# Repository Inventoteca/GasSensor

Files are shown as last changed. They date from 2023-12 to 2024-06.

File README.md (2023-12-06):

# Gas Sensor
Sensor de nivel de gas para tanques estacionarios. Se coloca sobre 
el indicador de nivel y transmite las lectura de manera inalámbrica. 
Hay 2 versiones principales: uno que usa LoRa y otro que usa Sigfox.  

La versión LoRa no es viable porque necesita muchas estaciones disponibles.  
La versión Sigfox funciona.  

Debe funcionar durante 3 años continuos usando 2 baterías AA. 
Se necesita un consumo promedio de 4 mA o menos.

El diseño "sensor_sigfox_1.1" es una actualización de la versión 1 del sensor Sigfox. 
Se han realizado cmabios en hardware y software . Los cambios principales son:  
- los módulos están configurados en modo de bajo consumo
- la lectura del voltaje de alimentación se realiza con el hardware interno del microcontrolador (de esta forma se elimina un divisor de voltaje externo)
- cambio de sensor magnético (se descarta el AS5600 y se agrega el MLX90393)
- usar frecuencia de reloj de ultra-bajo consumo (32.768 kHz)
- se puede usar el generador de frecuencia interno, pero también se agrega un cristal y capacitores de carga para commparar el consumo
- eliminar booster
- agregar conector U.FL para antena y pad para soldar antena de alambre opcional (eliminar conector SMA)

El conector U.FL se usa en muchos dispositivos  
https://en.wikipedia.org/wiki/Hirose_U.FL  
https://learn.sparkfun.com/tutorials/three-quick-tips-about-using-ufl/all  
https://www.data-alliance.net/ufl-cables/  

Los cristales más baratos tienen encapsulado cilindrico  
https://www.lcsc.com/product-detail/Crystals_CREC-01-X-TB-11CHJRI032768000_C7462599.html  
Para facilitar el montaje se usarán cristales SMD aunque son un poco más grandes  
https://www.lcsc.com/product-detail/Crystals_huaxindianzi-DP2032K76812001_C17702403.html  

El microcontrolador es ATtiny826 (8kB, family 2, 20 pins). Se usan los siguiente pines:  
- alimentación VCC pin 1, GND pin 20
- I2C (TWI) SDA pin 10 PB1, SCL pin 11 PB0
- cristal TOSC1 pin 8 PB3, TOSC2 pin 9 PB2
- UART hay 2 puertos con pines configurables (Serial y Serial1) con TX, RX, XCK, XDIR en PC0, PC1, PC2, PC3 y PA1, PA2, PA3, PA4
https://datasheet.lcsc.com/lcsc/2309071123_Microchip-Tech-ATTINY826-XU_C3235639.pdf
https://github.com/SpenceKonde/megaTinyCore

Los componentes más baratos están en LCSC, luego DigiKey y en tercer lugar Mouser  

El sensor Hall se puede usar en modo I2C o SPI. Se usará el modo I2C

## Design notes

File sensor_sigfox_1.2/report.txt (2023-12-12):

Info: Procesando el símbolo 'C2:Capacitor_SMD:C_0805_2012Metric_Pad1.18x1.45mm_HandSolder'.
Info: Procesando el símbolo 'U2:Package_DFN_QFN:QFN-16-1EP_3x3mm_P0.5mm_EP1.7x1.7mm'.
Info: Procesando el símbolo 'U1:Package_DFN_QFN:VQFN-20-1EP_3x3mm_P0.4mm_EP1.7x1.7mm'.
Info: Procesando el símbolo 'R4:Resistor_SMD:R_0805_2012Metric_Pad1.20x1.40mm_HandSolder'.
Info: Procesando el símbolo 'R3:Resistor_SMD:R_0805_2012Metric_Pad1.20x1.40mm_HandSolder'.
Info: Procesando el símbolo 'R2:Resistor_SMD:R_0805_2012Metric_Pad1.20x1.40mm_HandSolder'.
Info: Procesando el símbolo 'R1:Resistor_SMD:R_0805_2012Metric_Pad1.20x1.40mm_HandSolder'.
Info: Procesando el símbolo 'J4:Connector_Coaxial:U.FL_Hirose_U.FL-R-SMT-1_Vertical'.
Info: Procesando el símbolo 'J3:Connector_Pin:Pin_D0.9mm_L10.0mm_W2.4mm_FlatFork'.
Info: Procesando el símbolo 'J2:Connector_PinHeader_2.54mm:PinHeader_1x07_P2.54mm_Vertical'.
Info: Procesando el símbolo 'IC1:WSSFM11R2DAT:WSSFM11R2DAT'.
Info: Procesando el símbolo 'J1:Battery:BatteryHolder_Keystone_2468_2xAAA'.
Info: Procesando el símbolo 'C3:Capacitor_SMD:C_0805_2012Metric_Pad1.18x1.45mm_HandSolder'.
Info: Procesando el símbolo 'C1:Capacitor_SMD:C_0805_2012Metric_Pad1.18x1.45mm_HandSolder'.
Info: Procesando el símbolo 'Y1:Crystal:Crystal_C26-LF_D2.1mm_L6.5mm_Vertical'.
Info: Procesando el símbolo 'C4:Capacitor_SMD:C_0805_2012Metric_Pad1.18x1.45mm_HandSolder'.
Info: Procesando el símbolo 'C5:Capacitor_SMD:C_0805_2012Metric_Pad1.18x1.45mm_HandSolder'.
Info: Procesando el símbolo 'C6:Capacitor_SMD:C_0805_2012Metric_Pad1.18x1.45mm_HandSolder'.
Info: Procesando el símbolo 'D1:LED_SMD:LED_0603_1608Metric_Pad1.05x0.95mm_HandSolder'.
U1 pin 11 reconectado de /SCL a Net-(U1-PB0).
U1 pin 12 reconectado de unconnected-(U1-PC0-Pad12) a Net-(U1-PB2).
U1 pin 13 reconectado de unconnected-(U1-PC1-Pad13) a /SDA.
U1 pin 14 reconectado de unconnected-(U1-PC2-Pad14) a /SCL.
Añadir red unconnected-(U1-PC0-Pad15).
U1 pin 15 reconectado de unconnected-(U1-PC3-Pad15) a unconnected-(U1-PC0-Pad15).
Añadir red unconnected-(U1-PC1-Pad16).
U1 pin 16 reconectado de Net-(U1-~{RESET}/PA0) a unconnected-(U1-PC1-Pad16).
Añadir red unconnected-(U1-PC2-Pad17).
U1 pin 17 reconectado de /SF_RX a unconnected-(U1-PC2-Pad17).
Añadir red unconnected-(U1-PC3-Pad18).
U1 pin 18 reconectado de /SF_TX a unconnected-(U1-PC3-Pad18).
U1 pin 19 reconectado de unconnected-(U1-PA3-Pad19) a Net-(U1-~{RESET}/PA0).
U1 pin 20 reconectado de GND a /SF_RX.
U1 pin 21 conectado a GND.
Y1 pin 1 reconectado de Net-(U1-PB3) a Net-(U1-PB0).
U1 pin 5 reconectado de unconnected-(U1-PA7-Pad5) a Net-(U1-PA4).
Añadir red Net-(U1-PB0).
C3 pin 2 reconectado de Net-(U1-PB3) a Net-(U1-PB0).
Huella U1 cambiada de 'Package_DFN_QFN:QFN-24-1EP_3x3mm_P0.4mm_EP1.75x1.6mm_ThermalVias' a 'Package_DFN_QFN:VQFN-20-1EP_3x3mm_P0.4mm_EP1.7x1.7mm'.
U1 propiedades actualizadas.
U1 pin 1 reconectado de VCC a /SF_TX.
Añadir red unconnected-(U1-PA3-Pad2).
U1 pin 2 reconectado de Net-(U1-PA4) a unconnected-(U1-PA3-Pad2).
U1 pin 3 reconectado de unconnected-(U1-PA5-Pad3) a GND.
U1 pin 4 reconectado de Net-(IC1-RST_N) a VCC.
U1 pin 10 reconectado de /SDA a unconnected-(U1-PB4-Pad10).
Añadir red unconnected-(U1-PA5-Pad6).
U1 pin 6 reconectado de unconnected-(U1-PB5-Pad6) a unconnected-(U1-PA5-Pad6).
U1 pin 7 reconectado de unconnected-(U1-PB4-Pad7) a Net-(IC1-RST_N).
Añadir red unconnected-(U1-PA7-Pad8).
U1 pin 8 reconectado de Net-(U1-PB3) a unconnected-(U1-PA7-Pad8).
Añadir red unconnected-(U1-PB5-Pad9).
U1 pin 9 reconectado de Net-(U1-PB2) a unconnected-(U1-PB5-Pad9).
Añadir red unconnected-(U1-PB4-Pad10).

Info: Número de avisos: 0, errores: 0.

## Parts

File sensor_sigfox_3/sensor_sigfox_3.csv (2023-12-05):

Id | Designator | Package | Quantity | Designation | Supplier and ref
1 | C7,C3 | C_0805_2012Metric_Pad1.18x1.45mm_HandSolder | 2 | 22u
2 | L2 | L_0603_1608Metric_Pad1.05x0.95mm_HandSolder | 1 | 47n
3 | R14 | R_0603_1608Metric_Pad0.98x0.95mm_HandSolder | 1 | 0
4 | R13,R12,R6 | R_0603_1608Metric_Pad0.98x0.95mm_HandSolder | 3 | 330
5 | R11 | R_0603_1608Metric_Pad0.98x0.95mm_HandSolder | 1 | 2k
6 | R10,R7 | R_0603_1608Metric_Pad0.98x0.95mm_HandSolder | 2 | 10k
7 | R9,R3 | R_0603_1608Metric_Pad0.98x0.95mm_HandSolder | 2 | 100k
8 | R8,R1 | R_0603_1608Metric_Pad0.98x0.95mm_HandSolder | 2 | 470
9 | R5,R4 | R_0603_1608Metric_Pad0.98x0.95mm_HandSolder | 2 | 2.2k
10 | R2 | R_0603_1608Metric_Pad0.98x0.95mm_HandSolder | 1 | 220k
11 | C8 | C_0603_1608Metric_Pad1.08x0.95mm_HandSolder | 1 | 100p
12 | C6,C4 | C_0603_1608Metric_Pad1.08x0.95mm_HandSolder | 2 | 10u
13 | C5,C2,C1 | C_0603_1608Metric_Pad1.08x0.95mm_HandSolder | 3 | 100n
14 | L1 | L_Murata_LQH55DN_5.7x5.0mm | 1 | 4.7u
15 | J3 | PinHeader_1x03_P2.54mm_Vertical | 1 | debug
16 | D2 | D_SMA | 1 | SD103
17 | J1 | PinHeader_1x03_P2.54mm_Vertical | 1 | UDPI
18 | J2 | PinHeader_1x02_P2.54mm_Horizontal | 1 | Battery
19 | JP1 | SolderJumper-3_P1.3mm_Open_Pad1.0x1.5mm | 1 | Jumper_3_Open
20 | IC2 | WSSFM11R2DAT | 1 | WSSFM11R2DAT
21 | D1,D3,D4 | LED_0603_1608Metric_Pad1.05x0.95mm_HandSolder | 3 | LED_Small
22 | U3 | SOT-23-6 | 1 | MT3608
23 | IC1 | SOIC127P600X175-8N | 1 | AS5600-ASOM
24 | Q1 | TSOT-23-6 | 1 | DMC2053UVT
25 | U2 | SSOP-20_5.3x7.2mm_P0.65mm | 1 | ATtiny826-X

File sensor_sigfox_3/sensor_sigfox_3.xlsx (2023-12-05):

Id | Designator | Package | Quantity | Designation | Supplier and ref
1 | C5,C2,C1 | C_0603_1608Metric_Pad1.08x0.95mm_HandSolder | 3 | 100n
2 | C6,C4 | C_0603_1608Metric_Pad1.08x0.95mm_HandSolder | 2 | 10u
3 | C7,C3 | C_0805_2012Metric_Pad1.18x1.45mm_HandSolder | 2 | 22u
4 | C8 | C_0603_1608Metric_Pad1.08x0.95mm_HandSolder | 1 | 100p
5 | D1,D3,D4 | LED_0603_1608Metric_Pad1.05x0.95mm_HandSolder | 3 | LED_Small
6 | D2 | D_SMA | 1 | SS24
7 | IC1 | SOIC127P600X175-8N | 1 | AS5600-ASOM
8 | IC2 | WSSFM11R2DAT | 1 | WSSFM11R2DAT
9 | J1 | PinHeader_1x03_P2.54mm_Vertical | 1 | UDPI
10 | J2 | PinHeader_1x02_P2.54mm_Horizontal | 1 | Battery
11 | J3 | PinHeader_1x03_P2.54mm_Vertical | 1 | debug
12 | JP1 | SolderJumper-3_P1.3mm_Open_Pad1.0x1.5mm | 1 | Jumper_3_Open
13 | L1 | L_Murata_LQH55DN_5.7x5.0mm | 1 | 4.7u | https://www.lcsc.com/product-detail/Inductors-SMD_BC-Bao-Cheng-Elec-BCIHP0420SC-4R7M_C2921168.html
14 | L2 | L_0603_1608Metric_Pad1.05x0.95mm_HandSolder | 1 | 47n
15 | Q1 | TSOT-23-6 | 1 | DMC2053UVT
16 | R10,R7 | R_0603_1608Metric_Pad0.98x0.95mm_HandSolder | 2 | 10k
17 | R11 | R_0603_1608Metric_Pad0.98x0.95mm_HandSolder | 1 | 2k
18 | R13,R12,R6 | R_0603_1608Metric_Pad0.98x0.95mm_HandSolder | 3 | 330
19 | R14 | R_0603_1608Metric_Pad0.98x0.95mm_HandSolder | 1 | 0
20 | R2 | R_0603_1608Metric_Pad0.98x0.95mm_HandSolder | 1 | 220k
21 | R5,R4 | R_0603_1608Metric_Pad0.98x0.95mm_HandSolder | 2 | 2.2k
22 | R8,R1 | R_0603_1608Metric_Pad0.98x0.95mm_HandSolder | 2 | 470
23 | R9,R3 | R_0603_1608Metric_Pad0.98x0.95mm_HandSolder | 2 | 100k
24 | U2 | SSOP-20_5.3x7.2mm_P0.65mm | 1 | ATtiny826-X
25 | U3 | SOT-23-6 | 1 | MT3608

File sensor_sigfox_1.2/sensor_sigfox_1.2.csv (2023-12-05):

Id | Designator | Package | Quantity | Designation | Supplier and ref
1 | R13,R12,R6 | R_0805_2012Metric_Pad1.20x1.40mm_HandSolder | 3 | 330
2 | J1 | PinHeader_1x03_P2.54mm_Vertical | 1 | UDPI
3 | J2 | PinHeader_1x02_P2.54mm_Horizontal | 1 | Battery
4 | JP1 | SolderJumper-3_P1.3mm_Open_Pad1.0x1.5mm | 1 | Jumper_3_Open
5 | C6,C4 | C_0805_2012Metric_Pad1.18x1.45mm_HandSolder | 2 | 10u
6 | C5,C1,C2 | C_0805_2012Metric_Pad1.18x1.45mm_HandSolder | 3 | 100n
7 | IC2 | WSSFM11R2DAT | 1 | WSSFM11R2DAT
8 | D1,D3,D4 | LED_0603_1608Metric_Pad1.05x0.95mm_HandSolder | 3 | LED_Small
9 | J4 | SMA_Samtec_SMA-J-P-X-ST-EM1_EdgeMount | 1 | Conn_Coaxial
10 | D2 | D_SOD-323_HandSoldering | 1 | SD103
11 | U3 | SOT-23-6 | 1 | MT3608
12 | R2 | R_0805_2012Metric_Pad1.20x1.40mm_HandSolder | 1 | 220k
13 | R9,R3 | R_0805_2012Metric_Pad1.20x1.40mm_HandSolder | 2 | 100k
14 | R10,R7 | R_0805_2012Metric_Pad1.20x1.40mm_HandSolder | 2 | 10k
15 | IC1 | SOIC127P600X175-8N | 1 | AS5600-ASOM
16 | Q1 | TSOT-23-6 | 1 | DMC2053UVT
17 | C7,C3 | C_0805_2012Metric_Pad1.18x1.45mm_HandSolder | 2 | 22u
18 | R1,R8 | R_0805_2012Metric_Pad1.20x1.40mm_HandSolder | 2 | 470
19 | R5,R4 | R_0805_2012Metric_Pad1.20x1.40mm_HandSolder | 2 | 2.2k
20 | U2 | SSOP-20_5.3x7.2mm_P0.65mm | 1 | ATtiny826-X
21 | L1 | L_0805_2012Metric_Pad1.15x1.40mm_HandSolder | 1 | 4.7u
22 | R11 | R_0805_2012Metric_Pad1.20x1.40mm_HandSolder | 1 | 2k

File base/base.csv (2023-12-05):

Id | Designator | Package | Quantity | Designation | Supplier and ref
1 | R7,R4,R3,R9,R5,R2,R8 | R_0805_2012Metric_Pad1.20x1.40mm_HandSolder | 7 | 10k
2 | C6,C1,C4 | C_0805_2012Metric_Pad1.18x1.45mm_HandSolder | 3 | 10u
3 | C8,C3,C7,C5 | C_0805_2012Metric_Pad1.18x1.45mm_HandSolder | 4 | 0.1u
4 | J3 | PinSocket_1x04_P2.54mm_Vertical | 1 | PROG
5 | SW2 | SW_Push_1P1T_NO_6x6mm_H9.5mm | 1 | Flash
6 | SW1 | SW_Push_1P1T_NO_6x6mm_H9.5mm | 1 | Reset
7 | R6,R1 | R_0805_2012Metric_Pad1.20x1.40mm_HandSolder | 2 | 150
8 | J2 | SMA_Samtec_SMA-J-P-X-ST-EM1_EdgeMount | 1 | RF
9 | U3 | Ai-Thinker-Ra-01-LoRa | 1 | Ai-Thinker-Ra-01
10 | U1 | TO-252-2 | 1 | AZ1117D-ADJ
11 | J1 | BarrelJack_Horizontal | 1 | Supply
12 | C2 | C_0805_2012Metric_Pad1.18x1.45mm_HandSolder | 1 | 22u
13 | U2 | ESP-07 | 1 | ESP-07

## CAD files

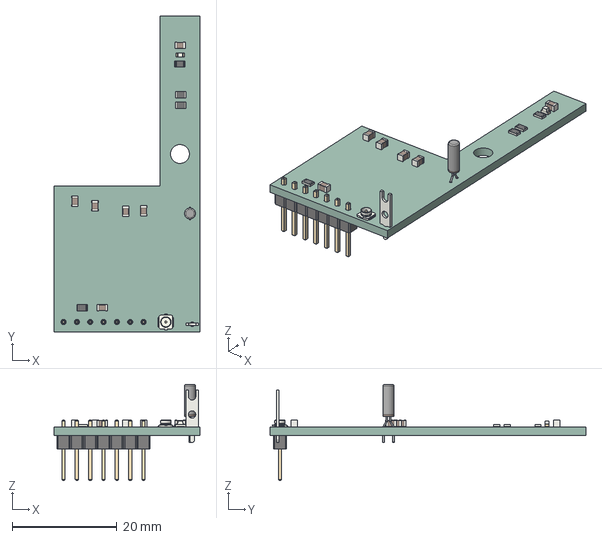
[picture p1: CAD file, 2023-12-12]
sensor_sigfox_1.2/sensor_sigfox_1.2.step
27.8 x 60.1 x 18.3 mm
_autosave-sensor_sigfox_1.1 PCB

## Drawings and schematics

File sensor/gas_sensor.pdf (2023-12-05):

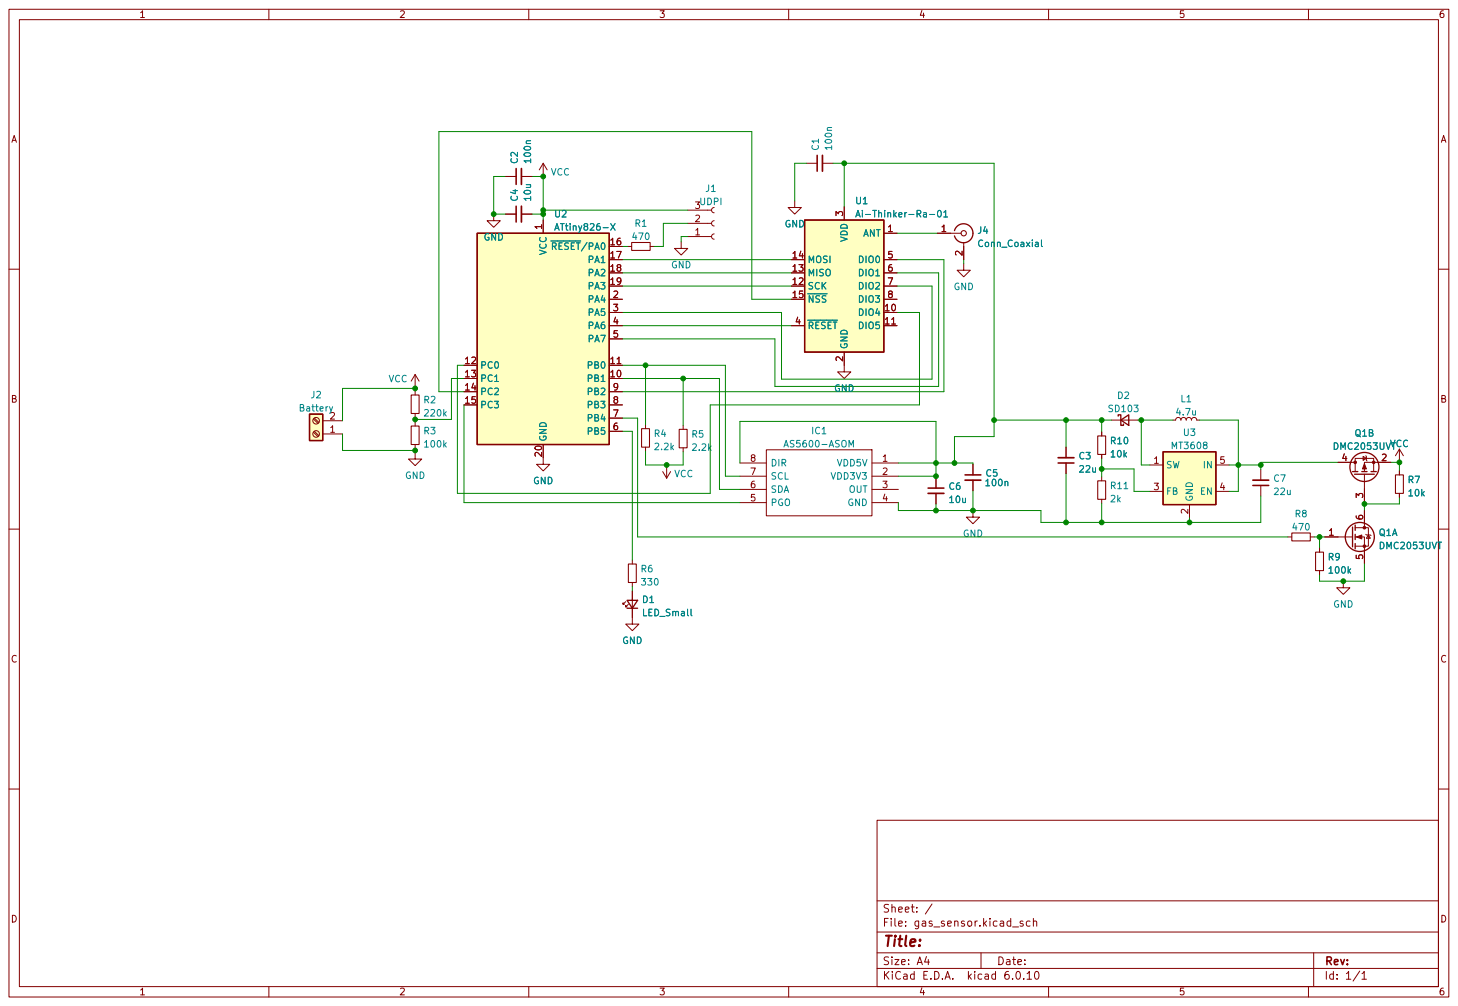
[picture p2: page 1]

1 PB1 10 PB0 11 PC0 12 PC1 13 PC2 14 PC3 15 ~{RESET}/PA016 PA1 17 PA2 18 PA3 19 PA4 2 GND 20 PA5 3 PA6 4 PA7 5 PB5 6 PB4 7 PB3 8 PB2 9 GND C410u C2100n GND

3 ~{RESET} 4 DIO0 5 DIO1 6 DIO2 7 DIO3 8 U1Ai-Thinker-Ra-01 GND

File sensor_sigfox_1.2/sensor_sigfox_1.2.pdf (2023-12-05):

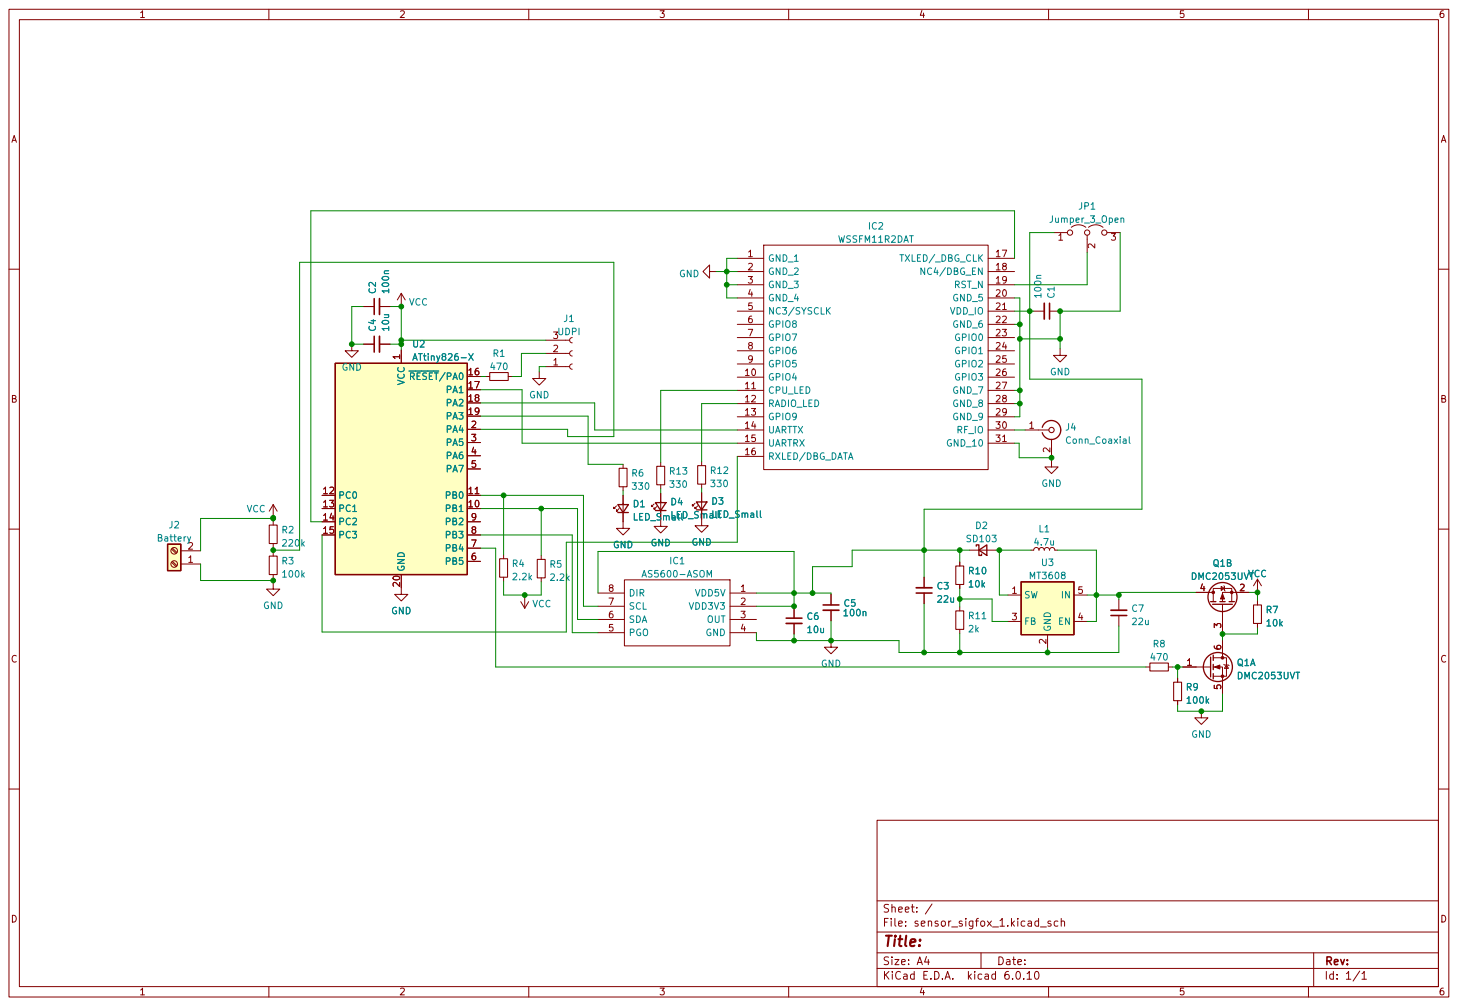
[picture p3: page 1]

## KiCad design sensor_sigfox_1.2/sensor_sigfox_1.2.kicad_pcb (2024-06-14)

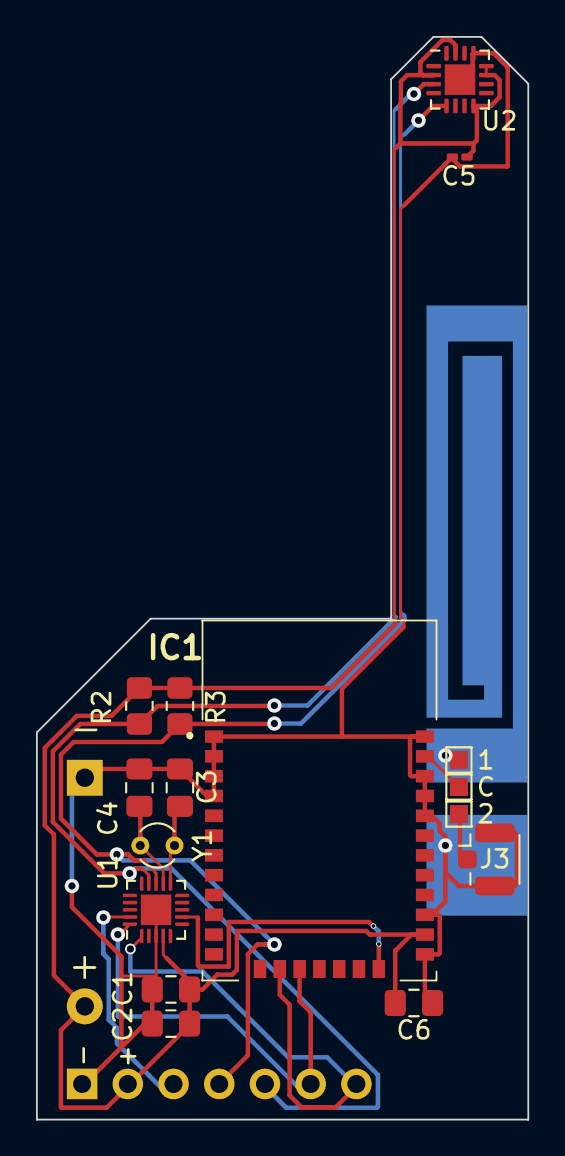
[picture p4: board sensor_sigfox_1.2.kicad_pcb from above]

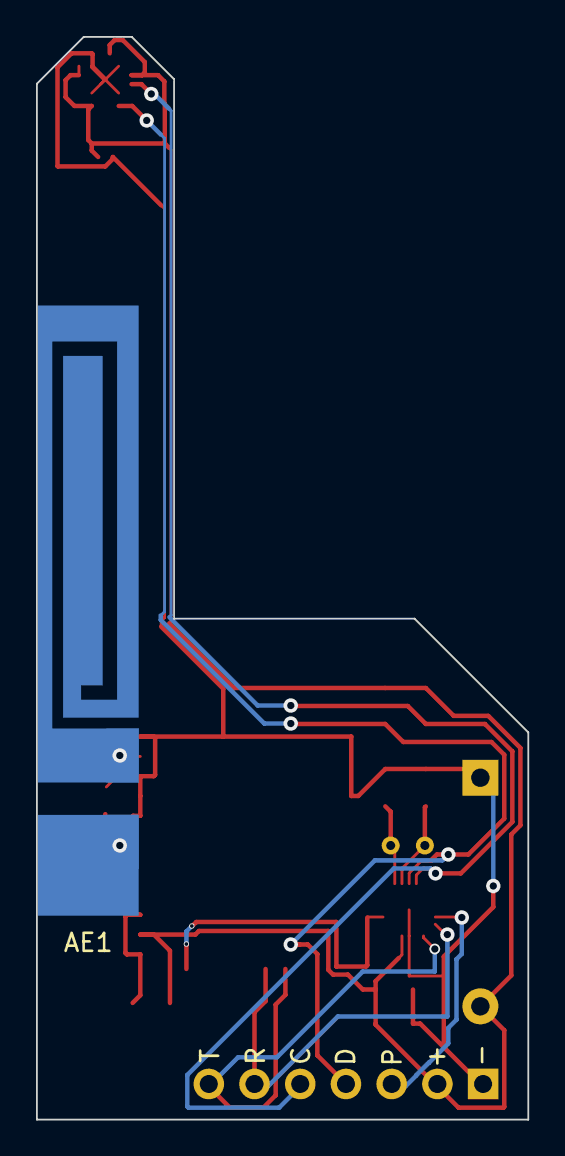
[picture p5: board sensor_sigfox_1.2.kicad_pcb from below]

Board: 2 copper layers, 27.3 x 60.1 mm, 19 parts (2 on the bottom side), 13 nets.

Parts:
1, 2: TestPoint; TestPoint_Pad_1.0x1.0mm
AE1: Antenna_Shield; antena1
C: TestPoint; TestPoint_Pad_1.0x1.0mm
C1: 10u; C_0805_2012Metric_Pad1.18x1.45mm_HandSolder
C2, C6: 100n; C_0805_2012Metric_Pad1.18x1.45mm_HandSolder
C3, C4: 20p; C_0805_2012Metric_Pad1.18x1.45mm_HandSolder
C5: 100n; C_0201_0603Metric_Pad0.64x0.40mm_HandSolder
IC1: WSSFM11R2DAT
J1: Battery; BatteryHolder_Keystone_2468_2xAAA
J2: Conn_01x07_Socket; PinHeader_1x07_P2.54mm_Vertical
J3: Conn_Coaxial; U.FL_Hirose_U.FL-R-SMT-1_Vertical
R2, R3: 2.2k; R_0805_2012Metric_Pad1.20x1.40mm_HandSolder
U1: ATtiny826-X; VQFN-20-1EP_3x3mm_P0.4mm_EP1.7x1.7mm
U2: MLX90393; QFN-16-1EP_3x3mm_P0.5mm_EP1.7x1.7mm
Y1: 32.768 kHz; Crystal_C26-LF_D2.1mm_L6.5mm_Vertical

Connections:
/SCL: J2.5, R2.1, U1.14 (PB0), U2.3 (SCL/SCLK)
/SDA: J2.4, R3.1, U1.13 (PB1), U2.5 (SDA/MOSI)
/SF_RX: IC1.15 (UARTRX), J2.6, U1.20 (PA1)
/SF_TX: IC1.14 (UARTTX), J2.7, U1.1 (PA2)
GND: AE1.2 (Shield), C1.1, C2.1, C3.1, C4.1, C5.1, C6.1, IC1.1 (GND_1), IC1.2 (GND_2), IC1.3 (GND_3), IC1.4 (GND_4), IC1.20 (GND_5), IC1.22 (GND_6), IC1.27 (GND_7), IC1.28 (GND_8), IC1.29 (GND_9), IC1.31 (GND_10), J1.1, J2.1, J3.2 (Ext), U1.3 (GND), U1.21 (GND), U2.13 (VSS), U2.17 (PAD)
unnamed: 1.1, AE1.1 (A)
unnamed: C.1, IC1.30 (RF_IO)
unnamed: IC1.19 (RST_N), U1.7 (PA6)
unnamed: J2.3, U1.19 (~RESET/PA0)
unnamed: 2.1, J3.1 (In)
unnamed: C4.2, U1.12 (PB2), Y1.2
unnamed: C3.2, U1.11 (PB3), Y1.1
VCC: C1.2, C2.2, C5.2, C6.2, IC1.21 (VDD_IO), J1.2, J2.2, R2.2, R3.2, U1.4 (VCC), U2.2 (MS/CS), U2.8 (VDD_IO), U2.11 (A1), U2.12 (A0), U2.15 (VDD)

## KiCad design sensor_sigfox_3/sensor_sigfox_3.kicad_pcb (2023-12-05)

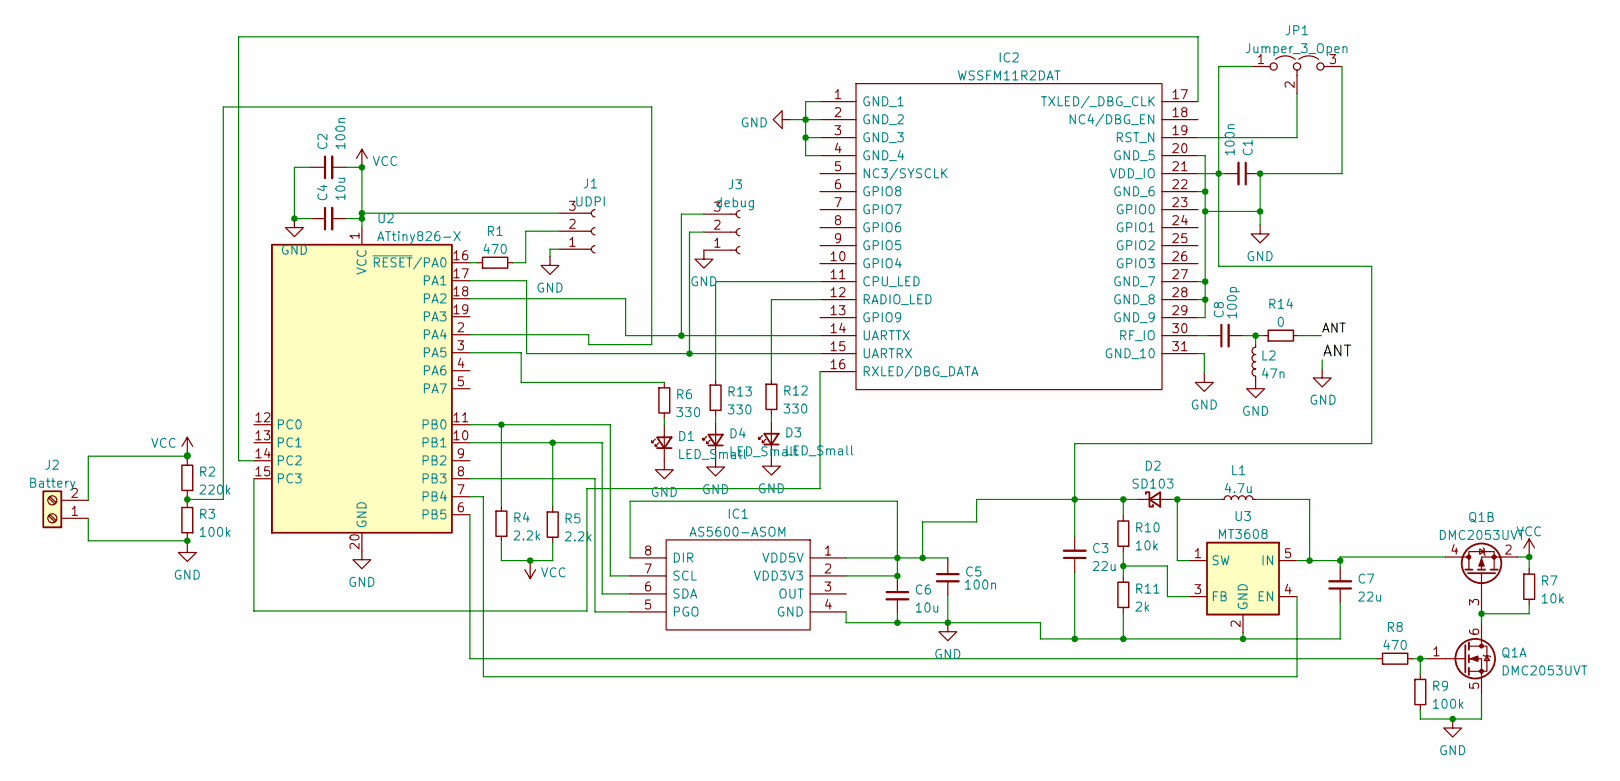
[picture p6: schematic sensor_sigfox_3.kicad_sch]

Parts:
C1, C2, C5: 100n; C_0603_1608Metric_Pad1.08x0.95mm_HandSolder
C3, C7: 22u; C_0805_2012Metric_Pad1.18x1.45mm_HandSolder
C4, C6: 10u; C_0603_1608Metric_Pad1.08x0.95mm_HandSolder
C8: 100p; C_0603_1608Metric_Pad1.08x0.95mm_HandSolder
D1, D3, D4: LED_Small; LED_0603_1608Metric_Pad1.05x0.95mm_HandSolder
D2: SD103; D_SMA
IC1: AS5600-ASOM; SOIC127P600X175-8N; Manufacturer_Part_Number AS5600-ASOM; Mouser Part Number 985-AS5600-ASOM
IC2: WSSFM11R2DAT; Manufacturer_Part_Number WSSFM11R2DAT
J1: UDPI; PinHeader_1x03_P2.54mm_Vertical
J2: Battery; PinHeader_1x02_P2.54mm_Horizontal
J3: debug; PinHeader_1x03_P2.54mm_Vertical
JP1: Jumper_3_Open; SolderJumper-3_P1.3mm_Open_Pad1.0x1.5mm
L1: 4.7u; L_Murata_LQH55DN_5.7x5.0mm
L2: 47n; L_0603_1608Metric_Pad1.05x0.95mm_HandSolder
Q1: DMC2053UVT; TSOT-23-6
R1, R8: 470; R_0603_1608Metric_Pad0.98x0.95mm_HandSolder
R2: 220k; R_0603_1608Metric_Pad0.98x0.95mm_HandSolder
R3, R9: 100k; R_0603_1608Metric_Pad0.98x0.95mm_HandSolder
R4, R5: 2.2k; R_0603_1608Metric_Pad0.98x0.95mm_HandSolder
R6, R12, R13: 330; R_0603_1608Metric_Pad0.98x0.95mm_HandSolder
R7, R10: 10k; R_0603_1608Metric_Pad0.98x0.95mm_HandSolder
R11: 2k; R_0603_1608Metric_Pad0.98x0.95mm_HandSolder
R14: 0; R_0603_1608Metric_Pad0.98x0.95mm_HandSolder
U2: ATtiny826-X; SSOP-20_5.3x7.2mm_P0.65mm
U3: MT3608; SOT-23-6

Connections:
GND: C1.1, C2.1, C3.1, C4.1, C5.2, C6.2, C7.1, D1.1 (K), D3.1 (K), D4.1 (K), IC1.4 (GND), IC2.1 (GND_1), IC2.2 (GND_2), IC2.3 (GND_3), IC2.4 (GND_4), IC2.20 (GND_5), IC2.22 (GND_6), IC2.27 (GND_7), IC2.28 (GND_8), IC2.29 (GND_9), IC2.31 (GND_10), J1.1, J2.1, J3.1, JP1.3 (B), L2.1, Q1.5 (S), R3.1, R9.2, R11.1, R14.2, U2.20 (GND), U3.2 (GND)
unnamed: C1.2, C3.2, C5.1, C6.1, D2.1 (K), IC1.1 (VDD5V), IC1.2 (VDD3V3), IC1.8 (DIR), IC2.21 (VDD_IO), JP1.1 (A), R10.2
unnamed: C7.2, L1.2, Q1.4 (D), U3.5 (IN)
unnamed: C8.2, L2.2, R14.1
unnamed: D1.2 (A), R6.2
unnamed: D2.2 (A), L1.1, U3.1 (SW)
unnamed: D3.2 (A), R12.2
unnamed: D4.2 (A), R13.2
unnamed: IC1.5 (PGO), U2.8 (PB3)
unnamed: IC1.6 (SDA), R5.1, U2.10 (PB1)
unnamed: IC1.7 (SCL), R4.1, U2.11 (PB0)
unnamed: IC2.11 (CPU_LED), R13.1
unnamed: IC2.12 (RADIO_LED), R12.1
unnamed: IC2.14 (UARTTX), J3.3, U2.18 (PA2)
unnamed: IC2.15 (UARTRX), J3.2, U2.17 (PA1)
unnamed: IC2.16 (RXLED/DBG_DATA), U2.15 (PC3)
unnamed: IC2.17 (TXLED/_DBG_CLK), U2.14 (PC2)
unnamed: IC2.19 (RST_N), JP1.2 (C)
unnamed: C8.1, IC2.30 (RF_IO)
unnamed: J1.2, R1.2
unnamed: Q1.1 (G), R8.2, R9.1
unnamed: Q1.3 (G), Q1.6 (D), R7.2
unnamed: R1.1, U2.16 (~RESET/PA0)
unnamed: R2.1, R3.2, U2.2 (PA4)
unnamed: R10.1, R11.2, U3.3 (FB)
unnamed: R6.1, U2.3 (PA5)
unnamed: R8.1, U2.6 (PB5)
unnamed: U2.7 (PB4), U3.4 (EN)
VCC: C2.2, C4.2, J1.3, J2.2, Q1.2 (S), R2.2, R4.2, R5.2, R7.1, U2.1 (VCC)

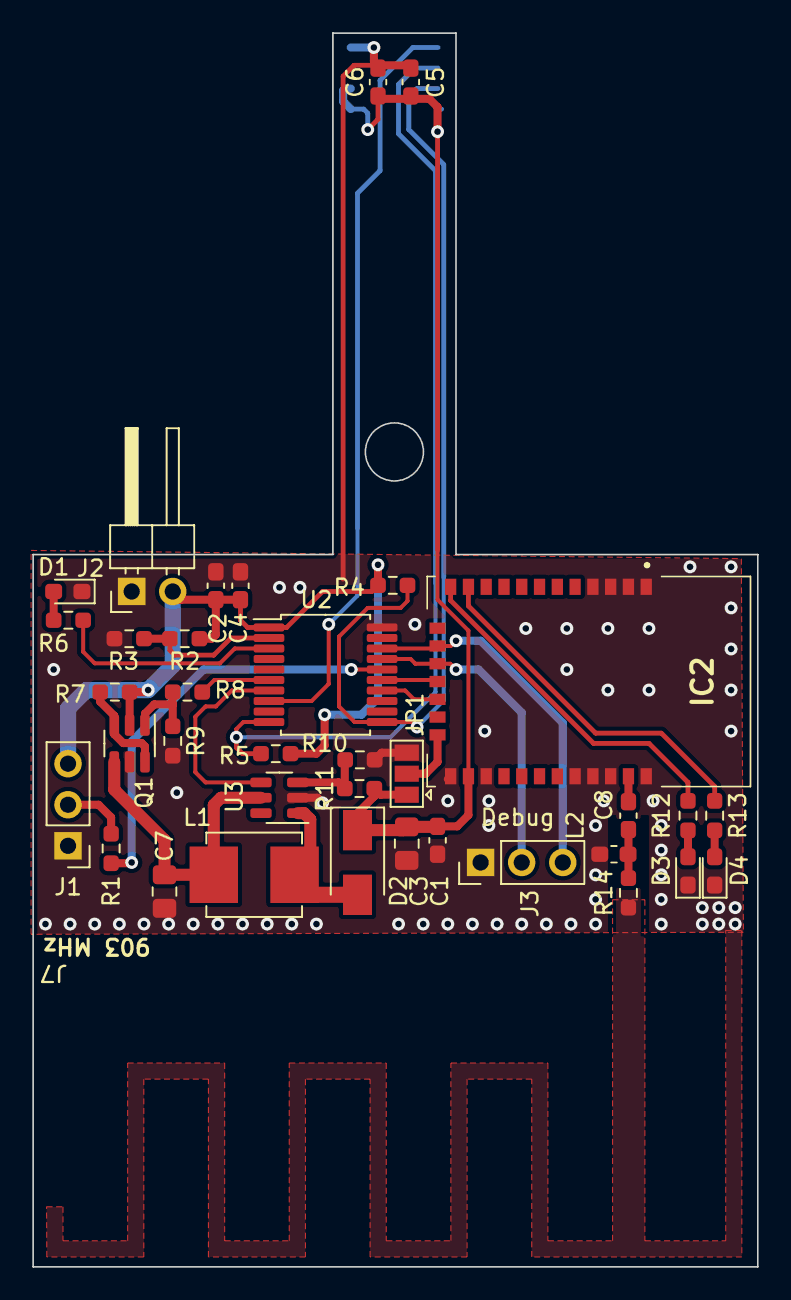
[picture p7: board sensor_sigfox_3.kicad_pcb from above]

Board: 2 copper layers, 44.8 x 76.3 mm, 37 parts (1 on the bottom side), 29 nets.

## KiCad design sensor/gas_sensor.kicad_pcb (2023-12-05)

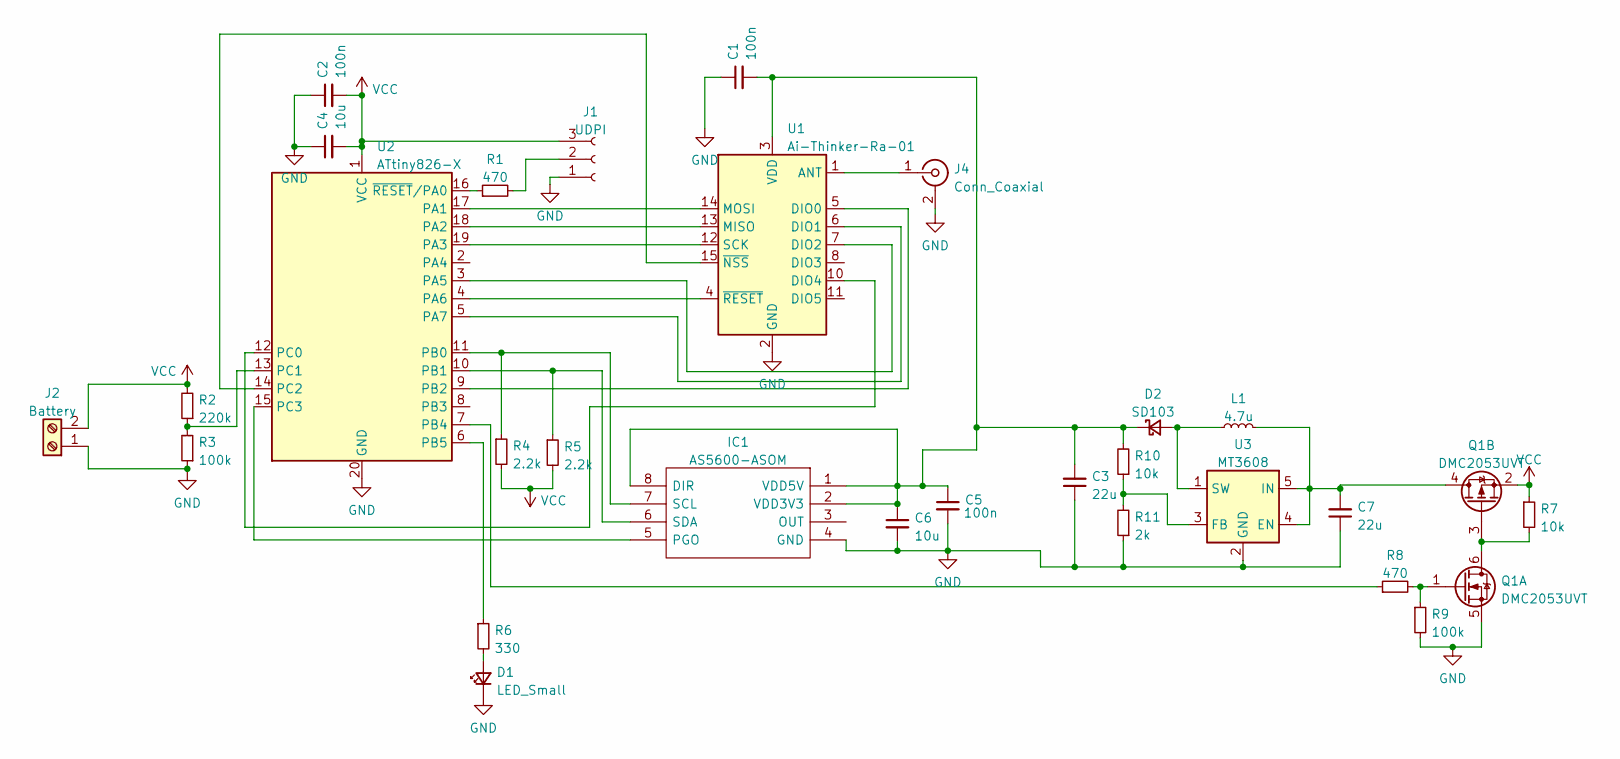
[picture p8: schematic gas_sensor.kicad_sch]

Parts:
C1, C2, C5: 100n; C_0805_2012Metric_Pad1.18x1.45mm_HandSolder
C3, C7: 22u; C_0805_2012Metric_Pad1.18x1.45mm_HandSolder
C4, C6: 10u; C_0805_2012Metric_Pad1.18x1.45mm_HandSolder
D1: LED_Small; LED_0603_1608Metric_Pad1.05x0.95mm_HandSolder
D2: SD103; D_SOD-323_HandSoldering
IC1: AS5600-ASOM; SOIC127P600X175-8N; Manufacturer_Part_Number AS5600-ASOM; Mouser Part Number 985-AS5600-ASOM
J1: UDPI; PinHeader_1x03_P2.54mm_Vertical
J2: Battery; PinHeader_1x02_P2.54mm_Horizontal
J4: Conn_Coaxial; SMA_Samtec_SMA-J-P-X-ST-EM1_EdgeMount
L1: 4.7u; L_0805_2012Metric_Pad1.15x1.40mm_HandSolder
Q1: DMC2053UVT; TSOT-23-6
R1, R8: 470; R_0805_2012Metric_Pad1.20x1.40mm_HandSolder
R2: 220k; R_0805_2012Metric_Pad1.20x1.40mm_HandSolder
R3, R9: 100k; R_0805_2012Metric_Pad1.20x1.40mm_HandSolder
R4, R5: 2.2k; R_0805_2012Metric_Pad1.20x1.40mm_HandSolder
R6: 330; R_0805_2012Metric_Pad1.20x1.40mm_HandSolder
R7, R10: 10k; R_0805_2012Metric_Pad1.20x1.40mm_HandSolder
R11: 2k; R_0805_2012Metric_Pad1.20x1.40mm_HandSolder
U1: Ai-Thinker-Ra-01; Ai-Thinker-Ra-01-LoRa
U2: ATtiny826-X; SSOP-20_5.3x7.2mm_P0.65mm
U3: MT3608; SOT-23-6

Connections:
GND: C1.1, C2.1, C3.1, C4.1, C5.2, C6.2, C7.1, D1.1 (K), IC1.4 (GND), J1.1, J2.1, J4.2 (Ext), Q1.5 (S), R3.1, R9.2, R11.1, U1.2 (GND), U1.9 (GND), U1.16 (GND), U2.20 (GND), U3.2 (GND)
unnamed: C1.2, C3.2, C5.1, C6.1, D2.1 (K), IC1.1 (VDD5V), IC1.2 (VDD3V3), IC1.8 (DIR), R10.2, U1.3 (VDD)
unnamed: D1.2 (A), R6.2
unnamed: D2.2 (A), L1.1, U3.1 (SW)
unnamed: IC1.5 (PGO), U2.15 (PC3)
unnamed: IC1.6 (SDA), R5.1, U2.10 (PB1)
unnamed: IC1.7 (SCL), R4.1, U2.11 (PB0)
unnamed: J1.2, R1.2
unnamed: J4.1 (In), U1.1 (ANT)
unnamed: Q1.1 (G), R8.2, R9.1
unnamed: Q1.3 (G), Q1.6 (D), R7.2
unnamed: C7.2, L1.2, Q1.4 (D), U3.4 (EN), U3.5 (IN)
unnamed: R1.1, U2.16 (~RESET/PA0)
unnamed: R2.1, R3.2, U2.13 (PC1)
unnamed: R6.1, U2.6 (PB5)
unnamed: R8.1, U2.7 (PB4)
unnamed: R10.1, R11.2, U3.3 (FB)
unnamed: U1.4 (~RESET), U2.4 (PA6)
unnamed: U1.5 (DIO0), U2.9 (PB2)
unnamed: U1.6 (DIO1), U2.5 (PA7)
unnamed: U1.7 (DIO2), U2.3 (PA5)
unnamed: U1.10 (DIO4), U2.12 (PC0)
unnamed: U1.12 (SCK), U2.19 (PA3)
unnamed: U1.13 (MISO), U2.18 (PA2)
unnamed: U1.14 (MOSI), U2.17 (PA1)
unnamed: U1.15 (~NSS), U2.14 (PC2)
VCC: C2.2, C4.2, J1.3, J2.2, Q1.2 (S), R2.2, R4.2, R5.2, R7.1, U2.1 (VCC)

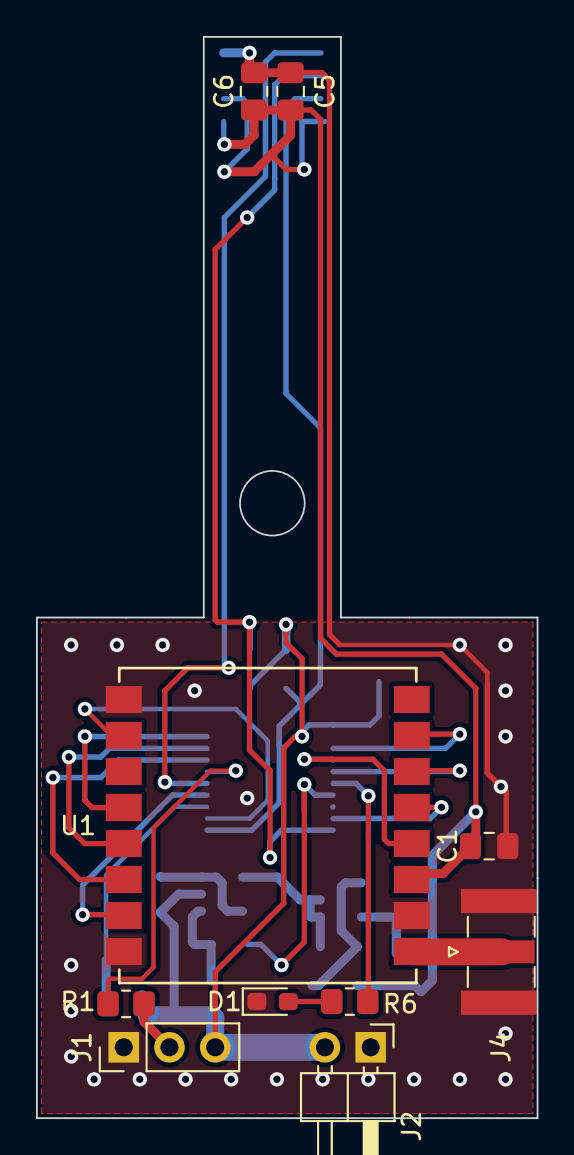
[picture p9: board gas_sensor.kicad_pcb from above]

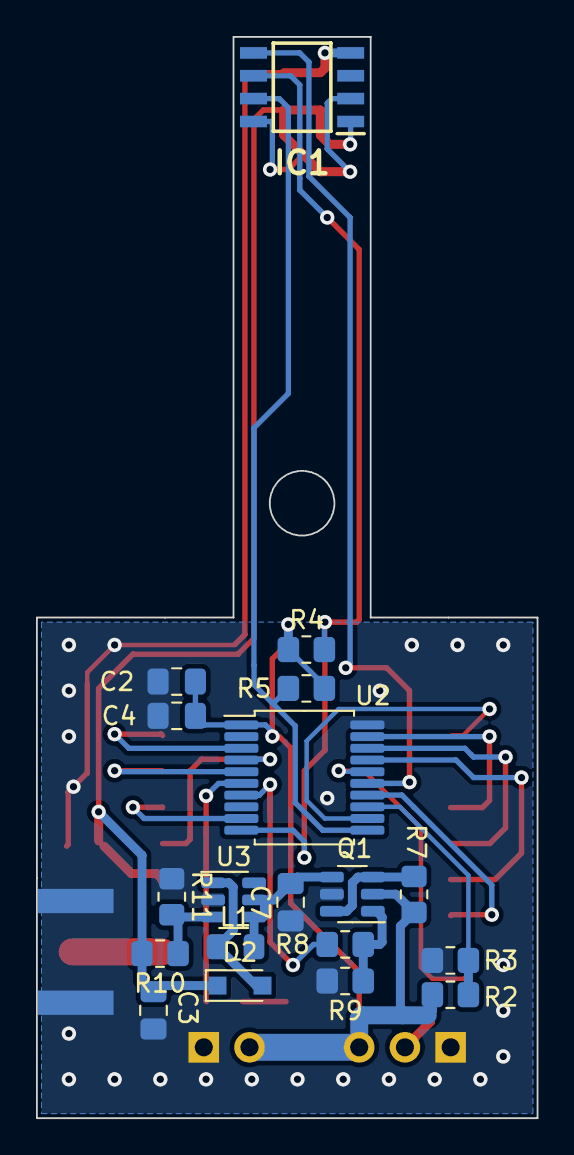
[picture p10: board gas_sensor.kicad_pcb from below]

Board: 2 copper layers, 27.8 x 60.1 mm, 29 parts (19 on the bottom side), 27 nets.

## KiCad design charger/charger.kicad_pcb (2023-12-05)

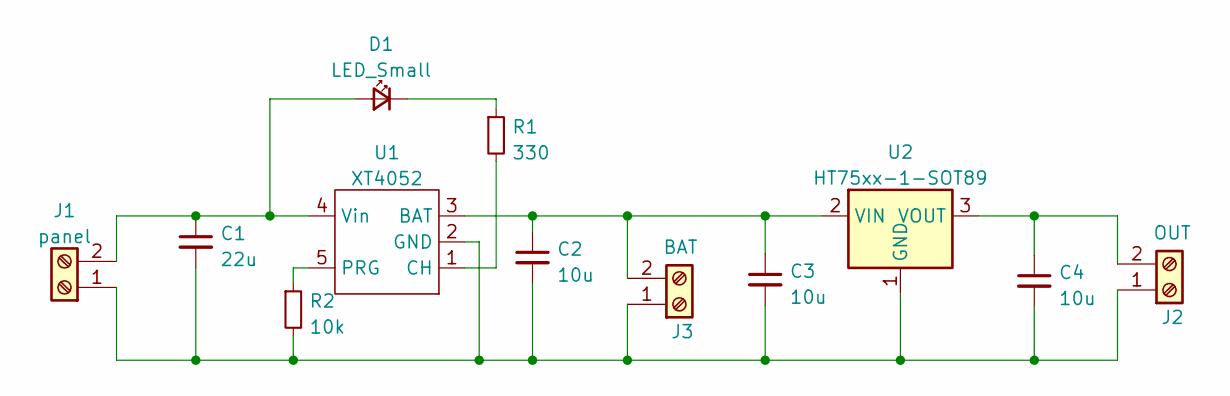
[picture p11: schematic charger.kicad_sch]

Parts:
C1: 22u; C_0805_2012Metric_Pad1.18x1.45mm_HandSolder
C2, C3, C4: 10u; C_0805_2012Metric_Pad1.18x1.45mm_HandSolder
D1: LED_Small; LED_0603_1608Metric_Pad1.05x0.95mm_HandSolder
J1: panel; TerminalBlock_bornier-2_P5.08mm
J2: OUT; TerminalBlock_bornier-2_P5.08mm
J3: BAT; TerminalBlock_bornier-2_P5.08mm
R1: 330; R_0805_2012Metric_Pad1.20x1.40mm_HandSolder
R2: 10k; R_0805_2012Metric_Pad1.20x1.40mm_HandSolder
U1: XT4052; SOT-23-5_HandSoldering
U2: HT75xx-1-SOT89; SOT-89-3

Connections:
unnamed: C1.1, D1.2 (A), J1.2, U1.4 (Vin)
unnamed: C1.2, C2.2, C3.2, C4.2, J1.1, J2.1, J3.1, R2.2, U1.2 (GND), U2.1 (GND)
unnamed: C2.1, C3.1, J3.2, U1.3 (BAT), U2.2 (VIN)
unnamed: C4.1, J2.2, U2.3 (VOUT)
unnamed: D1.1 (K), R1.1
unnamed: R1.2, U1.1 (CH)
unnamed: R2.1, U1.5 (PRG)

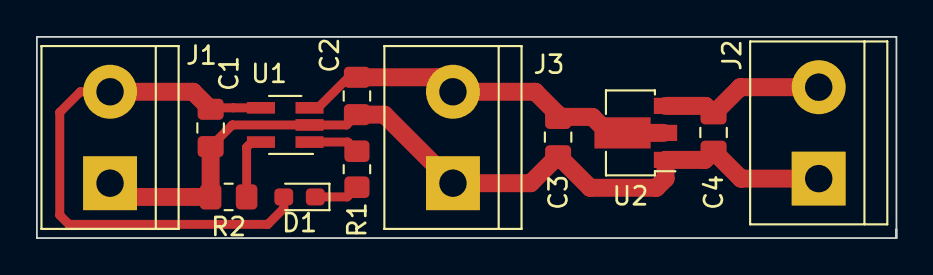
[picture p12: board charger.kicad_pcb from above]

Board: 2 copper layers, 47.8 x 11.2 mm, 12 parts (0 on the bottom side), 7 nets.

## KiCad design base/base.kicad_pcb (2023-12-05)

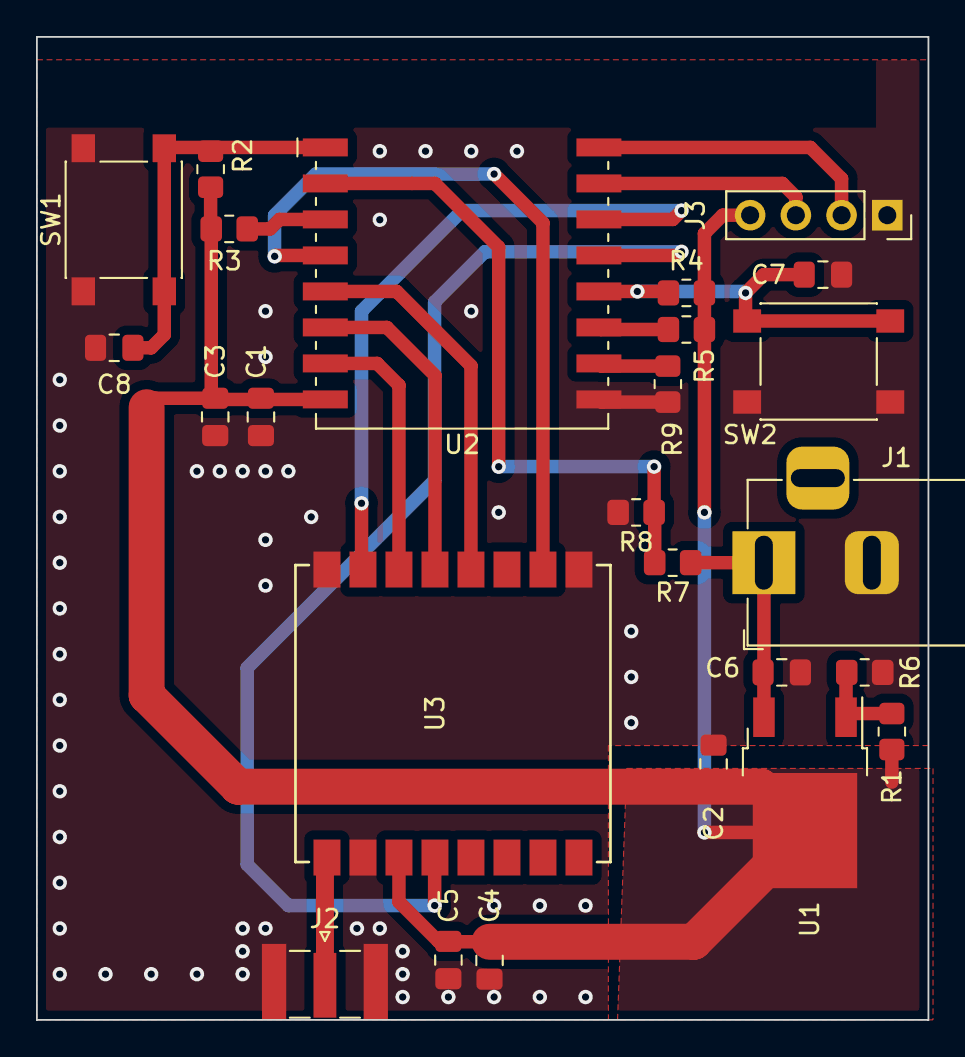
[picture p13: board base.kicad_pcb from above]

Board: 2 copper layers, 49.5 x 54.6 mm, 25 parts (0 on the bottom side), 19 nets.

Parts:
C1, C4, C6: 10u; C_0805_2012Metric_Pad1.18x1.45mm_HandSolder
C2: 22u; C_0805_2012Metric_Pad1.18x1.45mm_HandSolder
C3, C5, C7, C8: 0.1u; C_0805_2012Metric_Pad1.18x1.45mm_HandSolder
J1: Supply; BarrelJack_Horizontal
J2: RF; SMA_Samtec_SMA-J-P-X-ST-EM1_EdgeMount
J3: PROG; PinSocket_1x04_P2.54mm_Vertical
R1, R6: 150; R_0805_2012Metric_Pad1.20x1.40mm_HandSolder
R2, R3, R4, R5, R7, R9: 10k; R_0805_2012Metric_Pad1.20x1.40mm_HandSolder
R8: 3.9k; R_0805_2012Metric_Pad1.20x1.40mm_HandSolder
SW1: Reset; SW_Push_1P1T_NO_6x6mm_H9.5mm
SW2: Flash; SW_Push_1P1T_NO_6x6mm_H9.5mm
U1: AZ1117D-ADJ; TO-252-2
U2: ESP-07
U3: Ai-Thinker-Ra-01; Ai-Thinker-Ra-01-LoRa

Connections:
/BUSY: U2.4 (GPIO16), U3.10 (DIO4)
GND: C1.1, C2.1, C3.1, C4.1, C5.1, C6.1, C7.2, C8.1, J1.2, J2.2 (Ext), J3.1, R6.2, R8.2, R9.2, SW1.1, SW2.2, U2.9 (GND), U3.2 (GND), U3.9 (GND), U3.16 (GND)
unnamed: C1.2, C2.2, C3.2, C4.2, C5.2, J3.4, R1.1, R2.1, R3.1, R4.1, R5.1, U1.2 (VO), U2.8 (VCC), U3.3 (VDD)
unnamed: C6.2, J1.1, R7.1, U1.3 (VI)
unnamed: C7.1, R4.2, SW2.1, U2.12 (GPIO0)
unnamed: C8.2, R2.2, SW1.2, U2.1 (~RST)
unnamed: J2.1 (In), U3.1 (ANT)
unnamed: J3.2, U2.16 (GPIO1/TXD)
unnamed: J3.3, U2.15 (GPIO3/RXD)
unnamed: R1.2, R6.1, U1.1 (ADJ)
unnamed: R3.2, U2.3 (EN)
unnamed: R5.2, U2.11 (GPIO2)
unnamed: R7.2, R8.1, U2.2 (ADC)
unnamed: R9.1, U2.10 (GPIO15)
unnamed: U2.5 (GPIO14), U3.12 (SCK)
unnamed: U2.6 (GPIO12), U3.13 (MISO)
unnamed: U2.7 (GPIO13), U3.14 (MOSI)
unnamed: U2.13 (GPIO4), U3.4 (~RESET)
unnamed: U2.14 (GPIO5), U3.15 (~NSS)

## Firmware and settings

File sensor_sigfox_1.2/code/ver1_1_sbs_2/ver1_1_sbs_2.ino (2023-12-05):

#include <SPI.h>
#include <Ra01S.h>
#include <AS5600.h>
#include <EEPROM.h>
#include <avr/sleep.h>
//#define RF_FREQUENCY                                433000000 // Hz  center frequency
//#define RF_FREQUENCY                                866000000 // Hz  center frequency
#define RF_FREQUENCY                                915000000 // Hz  center frequency
#define TX_OUTPUT_POWER                             22        // dBm tx output power
#define LORA_BANDWIDTH                              4         // bandwidth
                                                              // 2: 31.25Khz
                                                              // 3: 62.5Khz
                                                              // 4: 125Khz
                                                              // 5: 250KHZ
                                                              // 6: 500Khz                                                               
#define LORA_SPREADING_FACTOR                       7         // spreading factor [SF5..SF12]
#define LORA_CODINGRATE                             1         // [1: 4/5,
                                                              //  2: 4/6,
                                                              //  3: 4/7,
                                                              //  4: 4/8]

#define LORA_PREAMBLE_LENGTH                        8         // Same for Tx and Rx
#define LORA_PAYLOADLENGTH                          0         // 0: Variable length packet (explicit header)
                                                              // 1..255  Fixed length packet (implicit header)
//#define PERIOD      10 
#define PERIOD      900 //15 min
#define ALA         200
#define LED         PIN_PB5
#define PWR         PIN_PB4
#define BAT         PIN_PC1

#define DIO1        PIN_PA7
#define DIO2        PIN_PA5

//#define SDIR        PIN_PB3
#define SPGO        PIN_PC3
#define SOUT        PIN_PC0

//#if 1
/*
 * for ATmega328/2560
 * VCC    3V3/3V3
 * GND    GND/GND
 * SCK    13/52
 * MISO   12/50
 * MOSI   11/51
 * NSS     5/5
 * RST     6/6
 * BUSY    7/7
 */
uint16_t ang_old=0, ang=0, bat=0;
uint8_t txData[9], rxData[4];
uint8_t rxLen=0, hops=0;
volatile uint16_t count=0;
boolean stat=0, note=0;
AS5600 encoder;
SX126x  lora(PIN_PC2,               //Port-Pin Output: SPI select
             PIN_PA6,               //Port-Pin Output: Reset 
             PIN_PB3                //Port-Pin Input:  Busy
             );

//#endif // ATmega328/2560

void RTC_init(void)
{
  /* Initialize RTC: */
  while (RTC.STATUS > 0)
  {
    ;                                   /* Wait for all register to be synchronized */
  }
  RTC.CLKSEL = RTC_CLKSEL_INT32K_gc;    /* 32.768kHz Internal Ultra-Low-Power Oscillator (OSCULP32K) */

  RTC.PITINTCTRL = RTC_PI_bm;           /* PIT Interrupt: enabled */

  RTC.PITCTRLA = RTC_PERIOD_CYC32768_gc /* RTC Clock Cycles 16384, resulting in 32.768kHz/16384 = 2Hz */
  | RTC_PITEN_bm;                       /* Enable PIT counter: enabled */
}

ISR(RTC_PIT_vect)
{
  RTC.PITINTFLAGS = RTC_PI_bm;          /* Clear interrupt flag by writing '1' (required) */
  count++;
}


void setup() 
{
  RTC_init(); 
  EEPROM.write(0, 'a');
  EEPROM.write(1, 'b');
  EEPROM.write(2, 'c');
  EEPROM.write(3, 4);
  pinMode(LED, OUTPUT);
  pinMode(PWR, OUTPUT);
  //pinMode(SDIR, OUTPUT);
  pinMode(SPGO, OUTPUT);
  pinMode(BAT, INPUT);
  pinMode(DIO1, INPUT);
  pinMode(DIO2, INPUT);
  pinMode(SOUT, INPUT);
  analogReference(INTERNAL2V048);
  txData[0] = EEPROM.read(0);        
  txData[1] = EEPROM.read(1);
  txData[2] = EEPROM.read(2);
  txData[3] = EEPROM.read(3);// ID, 4bytes
  digitalWrite(PWR, 1);//always on
  //digitalWrite(SDIR, 1);
  digitalWrite(SPGO, 1);
  SPI.begin();
  digitalWrite(LED, 1);
  delay(500);
  digitalWrite(LED, 0);
  delay(500);
  digitalWrite(LED, 1);
  delay(500);
  digitalWrite(LED, 0);
  delay(500);

  //lora.DebugPrint(true);

  int16_t ret = lora.begin(RF_FREQUENCY,              //frequency in Hz
                           TX_OUTPUT_POWER);          //tx power in dBm
  if (ret != ERR_NONE) while(1) {
    delay(1);
    digitalWrite(LED, 1);
    delay(100);
    digitalWrite(LED, 0);
    delay(100);
    }


  lora.LoRaConfig(LORA_SPREADING_FACTOR, 
                  LORA_BANDWIDTH, 
                  LORA_CODINGRATE, 
                  LORA_PREAMBLE_LENGTH, 
                  LORA_PAYLOADLENGTH, 
                  true,               //crcOn  
                  false);             //invertIrq
reg:
  if (lora.Send(txData, 4, SX126x_TXMODE_SYNC)) {
    //digitalWrite(LED, 1);
    //delay(1000);
    //digitalWrite(LED, 0);
     while(rxLen<=0){
      rxLen = lora.Receive(rxData, 4);
     }
    if((rxData[0]==txData[0])&&(rxData[1]==txData[1])&&(rxData[2]==txData[2])&&(rxData[3]==txData[3])){
      digitalWrite(LED, 1);
      delay(1000);
      digitalWrite(LED, 0);
     }
     else goto reg;
     
  } else {
    while(1){
      digitalWrite(LED, 1);
      delay(300);
      digitalWrite(LED, 0);
      delay(300);
    }
  }
  /*
  while(rxLen<=0){
    rxLen = lora.Receive(rxData, 4);
  }
  if((rxData[0]==txData[0])&&(rxData[1]==txData[1])&&(rxData[2]==txData[2])&&(rxData[3]==txData[3])){
    digitalWrite(LED, 1);
    delay(1000);
    digitalWrite(LED, 0);
  }
  else goto reg;*/
  ang_old = encoder.getAngle();
  set_sleep_mode(SLEEP_MODE_PWR_DOWN);  /* Set sleep mode to POWER DOWN mode */
  digitalWrite(PWR, 0);
  delay(5000);
}


void loop() 
{
 slp:
  sleep_cpu();
  if (count<PERIOD) goto slp;
  uint8_t txData[10];
  //sprintf((char *)txData, "Hello World %lu", millis());
  //ADC0.CTRLA |= ~ADC_ENABLE_bm;
  digitalWrite(PWR, 1);
  txData[0] = EEPROM.read(0);        
  txData[1] = EEPROM.read(1);
  txData[2] = EEPROM.read(2);
  txData[3] = EEPROM.read(3);// ID, 4bytes
  ang = encoder.getAngle();
  if (ang >4000){
    //ADC0.CTRLA &= ~ADC_ENABLE_bm;
    digitalWrite(PWR, 0);
    goto slp;
  }
  bat=analogRead(BAT);
  txData[5] = ang & 0xFF;         // extract least significant byte
  txData[4] = (ang >> 8) & 0xFF;  // extract most significant byte
  txData[7] = bat & 0xFF;         // extract least significant byte
  txData[6] = (bat >> 8) & 0xFF;  // extract most significant byte
  //uint8_t len = strlen((char *)txData);
  if (ang_old < ang){
    if ((ang - ang_old)>ALA){
      txData[8]=2;
      note=1;
    }
    else {
      txData[8]=0;
      note=0;
    }
  }
  else if (ang_old > ang){
    if ((ang_old - ang)>ALA){
      txData[8]=1;
      note=1;
    }
    else {
      txData[8]=0;
      note=0;
    }
  }
  else {
    txData[8]=0;
    note=0;
  }
  ang_old = ang;
  // Wait for transmission to complete
sending:  
  if (note==1){
    stat=lora.Send(txData, 9, SX126x_TXMODE_SYNC);
  }
  else{
    stat=lora.Send(txData, 8, SX126x_TXMODE_SYNC);
  }
  if(stat==0){//problem
    digitalWrite(LED, 1);
    delay(5000);
    digitalWrite(LED, 0);
    //delay(300);
    //digitalWrite(LED, 1);
    //delay(300);
    //digitalWrite(LED, 0);
  }
  else{
    hops++;
    unsigned long start_time=millis();
    while((rxLen<=0)&&((millis()-start_time)<3000)){
      rxLen = lora.Receive(rxData, 4); 
      if((rxData[0]==txData[0])&&(rxData[1]==txData[1])&&(rxData[2]==txData[2])&&(rxData[3]==txData[3])){
        break;
      }
      else rxLen=-1;
    }
    if(((millis()-start_time)>3000)&&(hops<3)){
      goto sending;
    }
    else(hops=0);
  }
  digitalWrite(PWR, 0);
  //ADC0.CTRLA &= ~ADC_ENABLE_bm;
  digitalWrite(LED, 1);
  delay(100);
  digitalWrite(LED, 0);
  count=0;
  
  // Do not wait for the transmission to be completed
  //lora.Send(txData, len, SX126x_TXMODE_ASYNC );

  //delay(2000);
}

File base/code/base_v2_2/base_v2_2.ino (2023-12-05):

#include <Arduino.h>
#include <ESP8266WiFi.h>
#include <ESP8266HTTPClient.h>
#include <ESP8266WebServer.h>
#include <EEPROM.h>
#include <ESP8266WiFiMulti.h>
ESP8266WiFiMulti wifiMulti;
#define DEVICE "ESP8266"
#define WIFI_AUTH_OPEN ENC_TYPE_NONE
#include <InfluxDbClient.h>
#include <InfluxDbCloud.h>

//#include <NTPClient.h>
//#include <WiFiUdp.h>
#include <Ra01S.h>
#include <SPI.h>

// Insert your network credentials
#define WIFI_SSID "INFINITUM50A3_2.4"
#define WIFI_PASSWORD "qbJQ52tb6e"
 #define INFLUXDB_URL "http://3.93.246.85:8086"
  #define INFLUXDB_TOKEN "E7LnF_IXZjUAAgLRrNYfJnXWgKMa_ie3t7kmZ5JNAcJWydrrwtseamCddxxLht-ioq6GvjelcOz2o467v_9ZBw=="
  #define INFLUXDB_ORG "0c414f2ddca87aa5"
  #define INFLUXDB_BUCKET "test"
   // Time zone info
  #define TZ_INFO "UTC-5"
  
  // Declare InfluxDB client instance with preconfigured InfluxCloud certificate
  InfluxDBClient client(INFLUXDB_URL, INFLUXDB_ORG, INFLUXDB_BUCKET, INFLUXDB_TOKEN, InfluxDbCloud2CACert);

// NTP servers the for time synchronization.
// For the fastest time sync find NTP servers in your area: https://www.pool.ntp.org/zone/
#define NTP_SERVER1  "pool.ntp.org"
#define NTP_SERVER2  "time.nis.gov"
#define WRITE_PRECISION WritePrecision::S
#define MAX_BATCH_SIZE 10
#define WRITE_BUFFER_SIZE 30


//#define RF_FREQUENCY                                433000000 // Hz  center frequency
//#define RF_FREQUENCY                                866000000 // Hz  center frequency
#define RF_FREQUENCY                                915000000 // Hz  center frequency
#define TX_OUTPUT_POWER                             22        // dBm tx output power
#define LORA_BANDWIDTH                              4         // bandwidth
                                                              // 2: 31.25Khz
                                                              // 3: 62.5Khz
                                                              // 4: 125Khz
                                                              // 5: 250KHZ
                                                              // 6: 500Khz 
#define LORA_SPREADING_FACTOR                       7         // spreading factor [SF5..SF12]
#define LORA_CODINGRATE                             1         // [1: 4/5,
                                                              //  2: 4/6,
                                                              //  3: 4/7,
                                                              //  4: 4/8]

#define LORA_PREAMBLE_LENGTH                        8         // Same for Tx and Rx
#define LORA_PAYLOADLENGTH                          0         // 0: Variable length packet (explicit header)
                                                              // 1..255  Fixed length packet (implicit header)

SX126x  lora(5,               //Port-Pin Output: SPI select
             4,               //Port-Pin Output: Reset 
             16                //Port-Pin Input:  Busy
             );

int iterations = 0;
int statusCode;
const char* ssid = "text";
const char* passphrase = "text";
String st;
String content;

ESP8266WebServer server(80);

bool testWifi(void)
{
  int c = 0;
  Serial.println("Waiting for Wifi to connect");
  while ( c < 120 ) {
    if (WiFi.status() == WL_CONNECTED)
    {
      return true;
    }
    delay(500);
    Serial.print("*");
    c++;
  }
  Serial.println("");
  Serial.println("Connect timed out, opening AP");
  return false;
}
 
void launchWeb()
{
  Serial.println("");
  if (WiFi.status() == WL_CONNECTED)
    Serial.println("WiFi connected");
  Serial.print("Local IP: ");
  Serial.println(WiFi.localIP());
  Serial.print("SoftAP IP: ");
  Serial.println(WiFi.softAPIP());
  createWebServer();
  // Start the server
  server.begin();
  Serial.println("Server started");
}
 
void setupAP(void)
{
  WiFi.mode(WIFI_STA);
  WiFi.disconnect();
  delay(100);
  int n = WiFi.scanNetworks();
  Serial.println("scan done");
  if (n == 0)
    Serial.println("no networks found");
  else
  {
    Serial.print(n);
    Serial.println(" networks found");
    for (int i = 0; i < n; ++i)
    {
      // Print SSID and RSSI for each network found
      Serial.print(i + 1);
      Serial.print(": ");
      Serial.print(WiFi.SSID(i));
      Serial.print(" (");
      Serial.print(WiFi.RSSI(i));
      Serial.print(")");
      Serial.println((WiFi.encryptionType(i) == ENC_TYPE_NONE) ? " " : "*");
      delay(10);
    }
  }
  Serial.println("");
  st = "<ol>";
  for (int i = 0; i < n; ++i)
  {
    // Print SSID and RSSI for each network found
    st += "<li>";
    st += WiFi.SSID(i);
    st += " (";
    st += WiFi.RSSI(i);
 
    st += ")";
    st += (WiFi.encryptionType(i) == ENC_TYPE_NONE) ? " " : "*";
    st += "</li>";
  }
  st += "</ol>";
  delay(100);
  WiFi.softAP("how2electronics", "");
  Serial.println("softap");
  launchWeb();
  Serial.println("over");
}
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

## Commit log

2023-12-05 subir diseño de la "base" LoRa
    [base-B_Cu.gbl, base-B_Mask.gbs, base-B_Paste.gbp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]
2023-12-05 subir diseño de cargador LoRa
    [charger.kicad_pcb, charger.kicad_sch]
2023-12-05 subir diseño de sensor LoRa
    [gas_sensor-B_Cu.gbl, gas_sensor-B_Mask.gbs, gas_sensor-B_Paste.gbp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]
2023-12-05 subir diseño de sensor sigfox v1
    [sensor_sigfox_1-B_Cu.gbl, sensor_sigfox_1-B_Mask.gbs, sensor_sigfox_1-B_Paste.gbp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]
2023-12-05 subir diseño de sensor sigfox v2
    [sensor_sigfox_2-B_Cu.gbl, sensor_sigfox_2-B_Mask.gbs, sensor_sigfox_2-B_Paste.gbp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]
2023-12-05 subir diseño de sensor sigfox v3
    [sensor_sigfox_3-B_Cu.gbl, sensor_sigfox_3-B_Mask.gbs, sensor_sigfox_3-B_Paste.gbp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]
2023-12-05 copiar diseño sigfox_1 y agregar otro sensor y cristal
    [sensor_sigfox_1.1-B_Cu.gbl, sensor_sigfox_1.1-B_Mask.gbs, sensor_sigfox_1.1-B_Paste.gbp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]
2023-12-06 iniciar conexiones a nuevos comps
    [sensor_sigfox_1.1.kicad_pcb, sensor_sigfox_1.1.kicad_sch]
2023-12-08 componentes borrados
    [sensor_sigfox_1.1.kicad_pcb, sensor_sigfox_1.1.kicad_sch]
2023-12-12 wip pcb new
    [sensor_sigfox_1.1.kicad_pcb, sensor_sigfox_1.1.kicad_sch]
2023-12-13 wip almost ready
    [sensor_sigfox_1.1.kicad_pcb, sensor_sigfox_1.1.kicad_sch]
2023-12-16 low almost 5.3mA, not rtc internal change
2023-12-18 pcb wip
    [sensor_sigfox_1.1.kicad_pcb]
2024-01-24 revision 1.1.1
    [sensor_sigfox_1.1.kicad_pcb]
2024-05-27 pcb 1.1
    [sensor_sigfox_1.1.kicad_pcb]
2024-05-28 WIP on main
    [sensor_sigfox_1.1.kicad_pcb, sensor_sigfox_1.1.kicad_sch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]
2024-05-30 gerber y conexiones int/trig
    [sensor_sigfox_1.1-B_Cu.gbl, sensor_sigfox_1.1-B_Mask.gbs, sensor_sigfox_1.1-B_Paste.gbp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]
2024-06-14 1.1 act
    [sensor_sigfox_1.1-B_Cu.gbl, sensor_sigfox_1.1-B_Mask.gbs, sensor_sigfox_1.1-B_Paste.gbp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]
2024-06-14 1.2 act
    [sensor_sigfox_1.2-B_Cu.gbl, sensor_sigfox_1.2-B_Mask.gbs, sensor_sigfox_1.2-B_Paste.gbp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]
2024-06-14 1.1 y 1.2 actualizados
    [sensor_sigfox_1.1.kicad_pcb, sensor_sigfox_1.1.kicad_sch, sensor_sigfox_1.2.kicad_pcb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]
